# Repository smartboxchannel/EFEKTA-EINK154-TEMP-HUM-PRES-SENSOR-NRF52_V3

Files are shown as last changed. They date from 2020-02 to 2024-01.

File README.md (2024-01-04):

# EFEKTA-EINK154-TEMP-HUM-PRESS-SENSOR-NRF52

Телеграм чат DIY Devices - https://t.me/diy_devices

Продажа DIY Устройств - https://t.me/diydevmart

Temperature and humidity sensor with 1.54 e-ink display.

#### Don't donate to me, it doesn't work in this world: https://paypal.me/efektalab , just buy:

fully assembled - $45.5

Video: https://youtu.be/T66y83lF-xg

More info at http://efektalab.com/eink154 

---

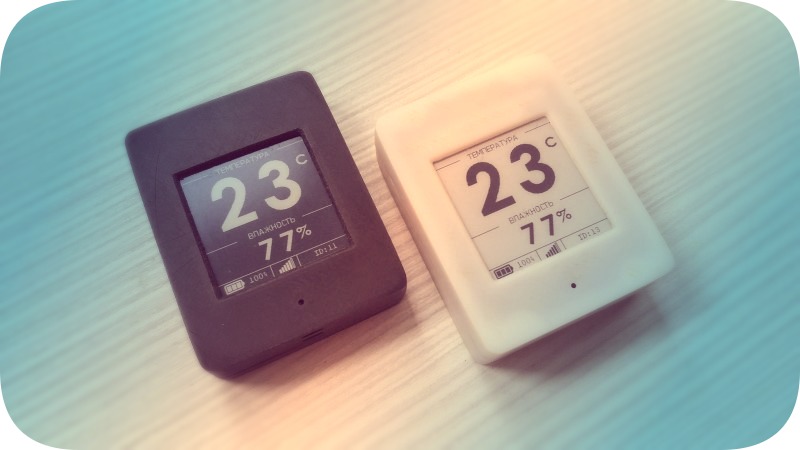
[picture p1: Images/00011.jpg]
EFEKTA EINK102 TEMP HUM MICRO SENSOR NRF52


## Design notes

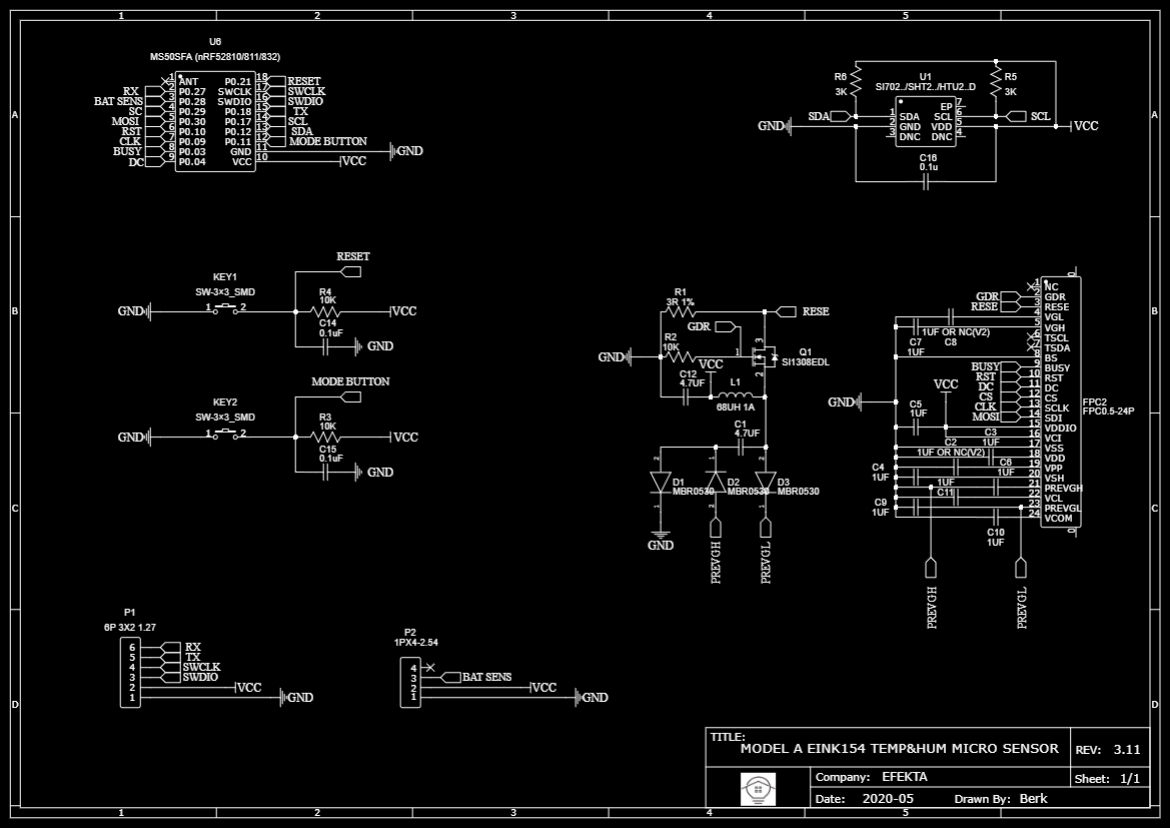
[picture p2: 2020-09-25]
Schematic_154v3T_A.png

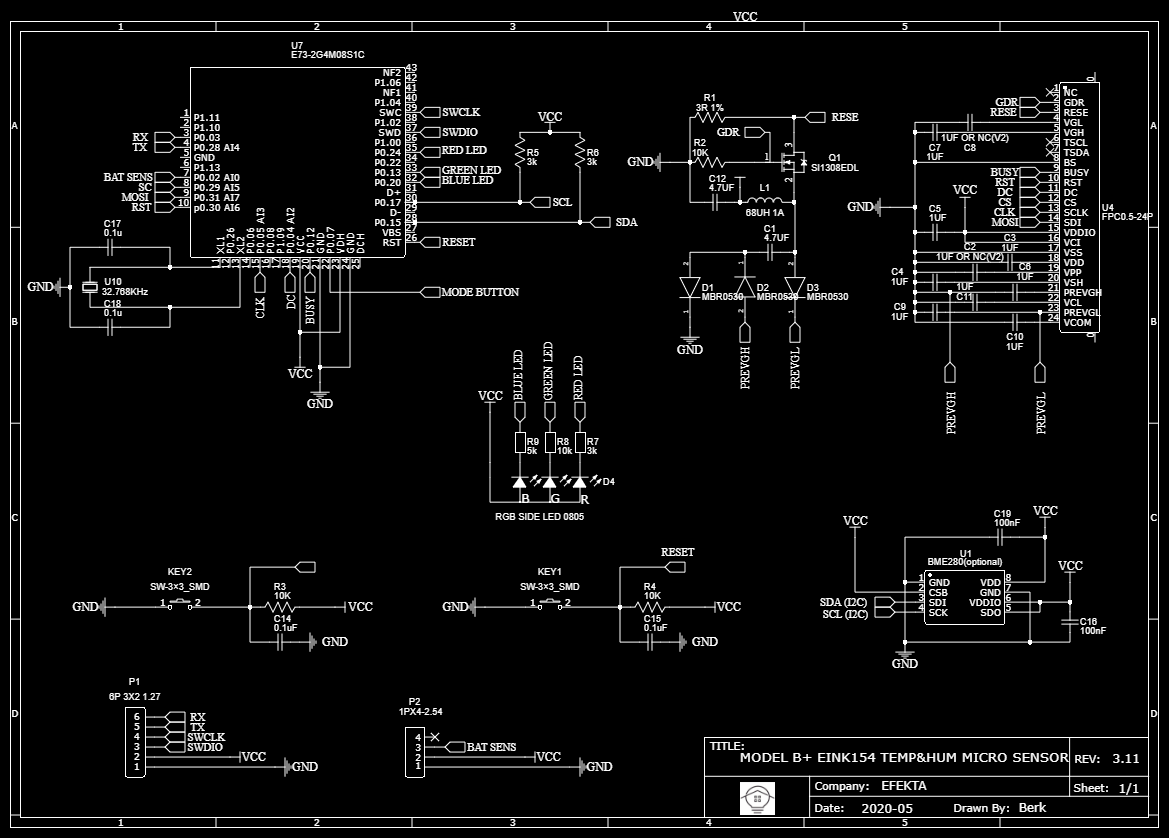
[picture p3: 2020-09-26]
SCHEME/Schematic_154v3T_B_plus.png

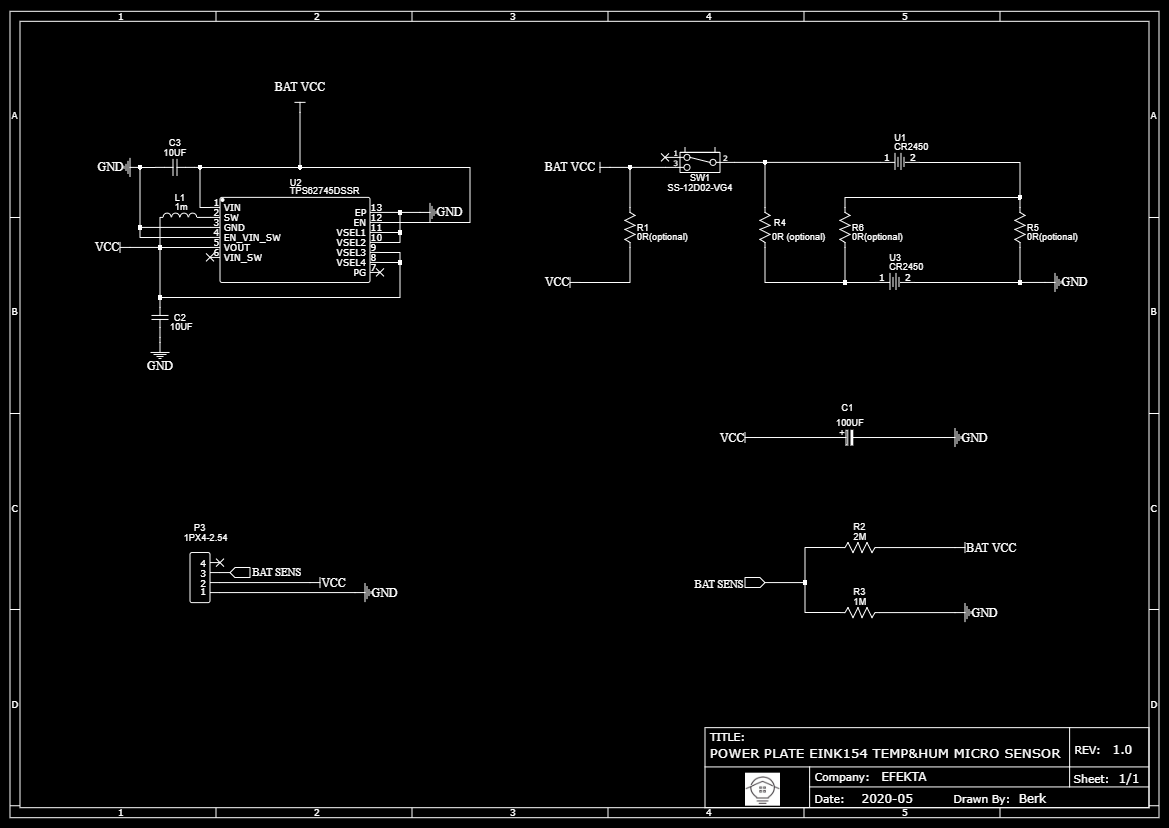
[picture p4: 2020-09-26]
SCHEME/Schematic_154v3B.png

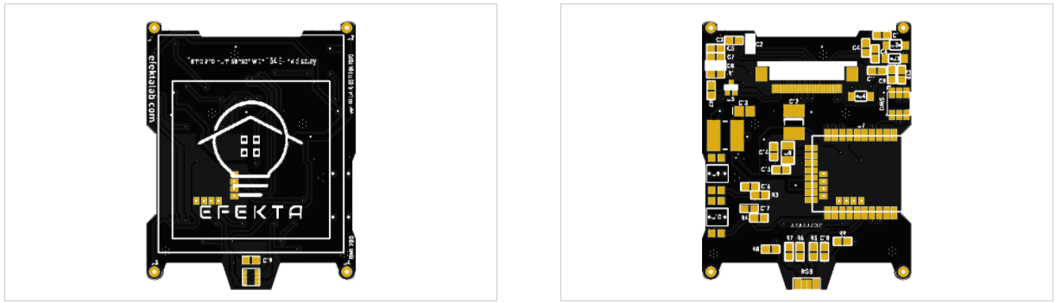
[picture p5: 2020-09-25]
Images/PCB_154v3T_B_plus.png

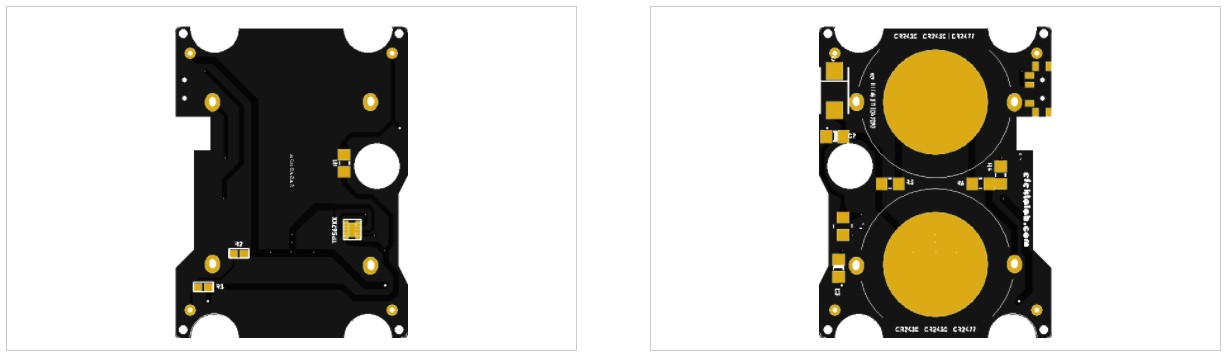
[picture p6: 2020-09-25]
Images/Bottom.jpg

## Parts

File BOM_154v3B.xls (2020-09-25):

ID | Name | Designator | Footprint | Quantity | URL
1 | CR2450 Holder | U1,U3 |  | 2 | https://lite.al/aQULIC
2 | TPS62745DSSR | U2 |  | 1 | https://lite.al/idG_8
3 | 1M | R2 | R0603 | 1 | https://lite.bz/_xQXIT
4 | 2M | R3 | R0603 | 1 | https://lite.bz/_xQXIT
5 | 0R | R1,R4,R5,R6 | R0603 | 4 | https://lite.al/wJH_j
6 | 10UF | C2,C3 | 1206 | 2 | https://lite.bz/Iua09
7 | 4.7UH | L1 | 1210 | 1 | https://lite.bz/1wrt-f
8 | 100uF | C13 | TANTAL 16V | 1 | https://lite.al/GeQyW
9 | SPDT MSK-12C02 SM | U2 |  | 1 | https://lite.al/ldulEe

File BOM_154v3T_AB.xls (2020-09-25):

ID | Name | Designator | Footprint | Quantity | URL
1 | GDEW0102T4 EINK1.54 |  |  | 1 | https://ali.ski/0pJURr
2 | GDEW0102T4 EINK1.54 |  |  | 1 | https://ali.ski/tIZry
3 | GDEW0102T4 EINK1.54 |  |  | 1 | https://ali.ski/WwyO3
4 | MS50SFA (nRF52810/811) | U7 | WIRELM-SMD_MS50SFA | 1 | https://ali.ski/8ya0Ob
5 | MS50SFA (nRF52811/832) | U7 | WIRELM-SMD_MS50SFA | 1 | https://ali.ski/gBDdnL
6 | E73-2G4M08S1C | U7 | WIRELM-SMD_E73-2G4M08S1C | 1 | https://ali.ski/ElGPh
7 | E73-2G4M08S1C | U7 | WIRELM-SMD_E73-2G4M08S1C | 1 | https://lite.al/qu4rE
8 | 4.7uF | C1,C12 | C0805 | 2 | https://ali.ski/7K6tZq
9 | 1uF (C2,C8 for V1 only) | C3,C4,C5,C6,C7,C9,C10,C11,C2,C8 | C0603 | 10 | https://lite.al/vsbI7N
10 | 100uF (if no SD Conv.) | C13 | TANTAL 10V | 1 | https://lite.al/mctVY
11 | 0.1uF | C14,C15,C16,C19 | C0603 | 5 | https://lite.al/eZrPr
12 | 22pF | C17,C18 | C0604 | 2 | https://lite.al/eZrPr
13 | SW-3×3_SMD | KEY1,KEY2 |  | 2 | https://lite.al/-qSRe
14 | 68uH or 100uH(V2) | L1 | D54 | 1 | https://lite.al/0V7Y2d
15 | 3R0 | R1 | R0603 | 1 | https://lite.al/wJH_j
16 | 10K | R2,R3,R4,R8 | R0603 | 4 | https://lite.al/wJH_j
17 | 3K | R7 | R0603 | 1 | https://lite.al/wJH_j
18 | 5K | R9 | R0603 | 1 | https://lite.al/wJH_j
19 | RGB SIDE LED | RGB | 1204 RGB | 1 | https://lite.bz/8izkIX
20 | MBR0530 | D1,D2,D3 | SOD-123 | 3 | https://lite.bz/aHLSRs
21 | FPC24 | U4 | FPC24 | 1 | https://lite.bz/tnF--R
22 | Si1304BD | U5 | SOT 323 | 1 | https://lite.al/apKJjP
23 | SHT20 | U1 |  | 1 | https://lite.bz/tGegZ
24 | Si7021 | U1 |  | 1 | https://lite.al/YWJ3c
25 | HTU21D | U1 |  | 1 | https://lite.bz/Qm9t30
26 | BME280 | U1 |  | 1 | https://lite.bz/FpaFS
27 | FC-135 | U10 | 3215 | 1 | https://lite.bz/DzxDDm

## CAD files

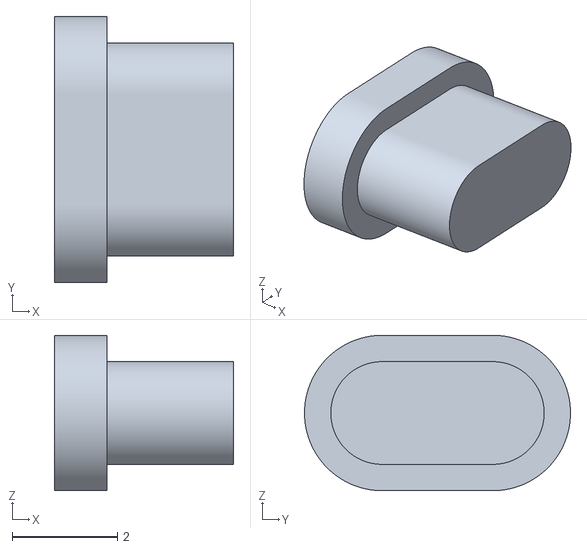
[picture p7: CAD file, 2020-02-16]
CASE/D_b.STL
3.40 x 5.05 x 2.95

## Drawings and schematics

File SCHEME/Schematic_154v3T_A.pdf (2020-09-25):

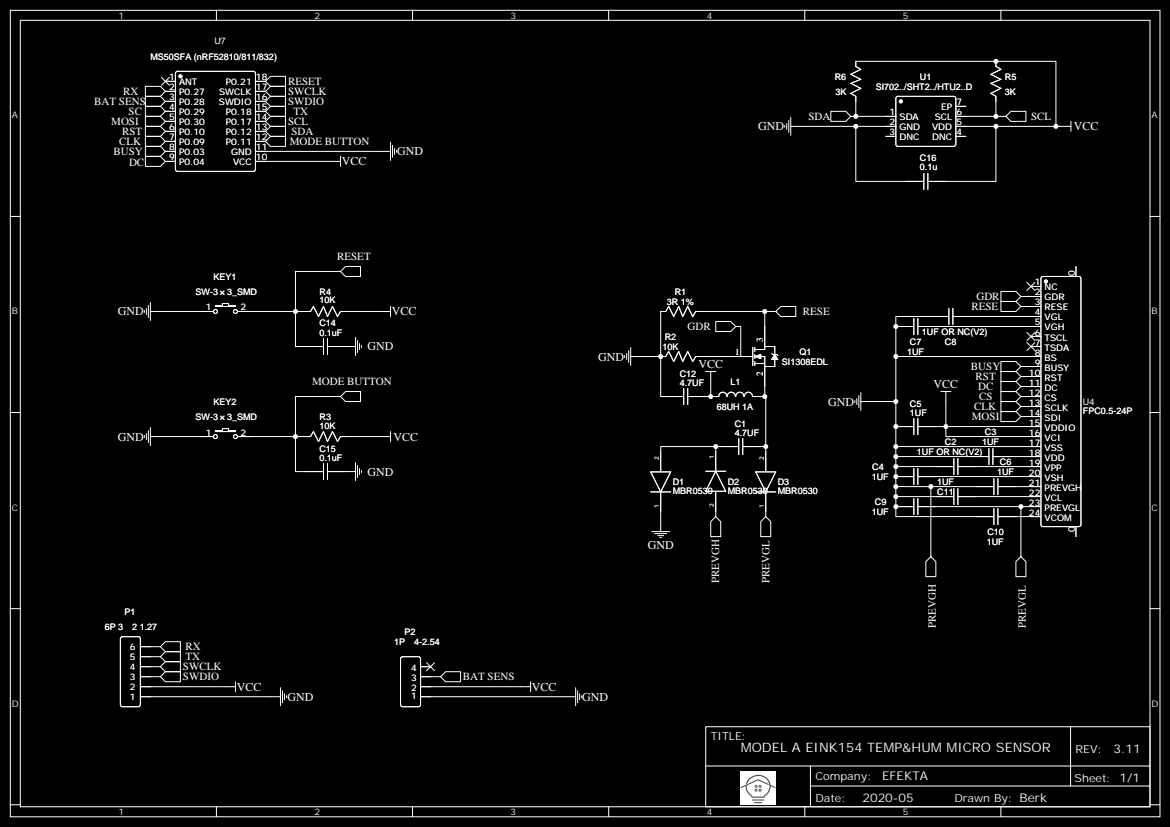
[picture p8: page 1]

VCC 10 GND 11 P0.11 12 P0.12 13 P0.17 14 P0.18 15 SWDIO 16 SWCLK 17 P0.21 18

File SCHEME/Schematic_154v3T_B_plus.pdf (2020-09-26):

RST 26 VBS 27 P0.15 28 D- 29 P0.17 30 D+ 31 P0.20 32 P0.13 33 P0.22 34 P0.24 35 P1.00 36 SWD 37 P1.02 38 SWC 39 P1.04 40 NF1 41 P1.06 42 NF2 43

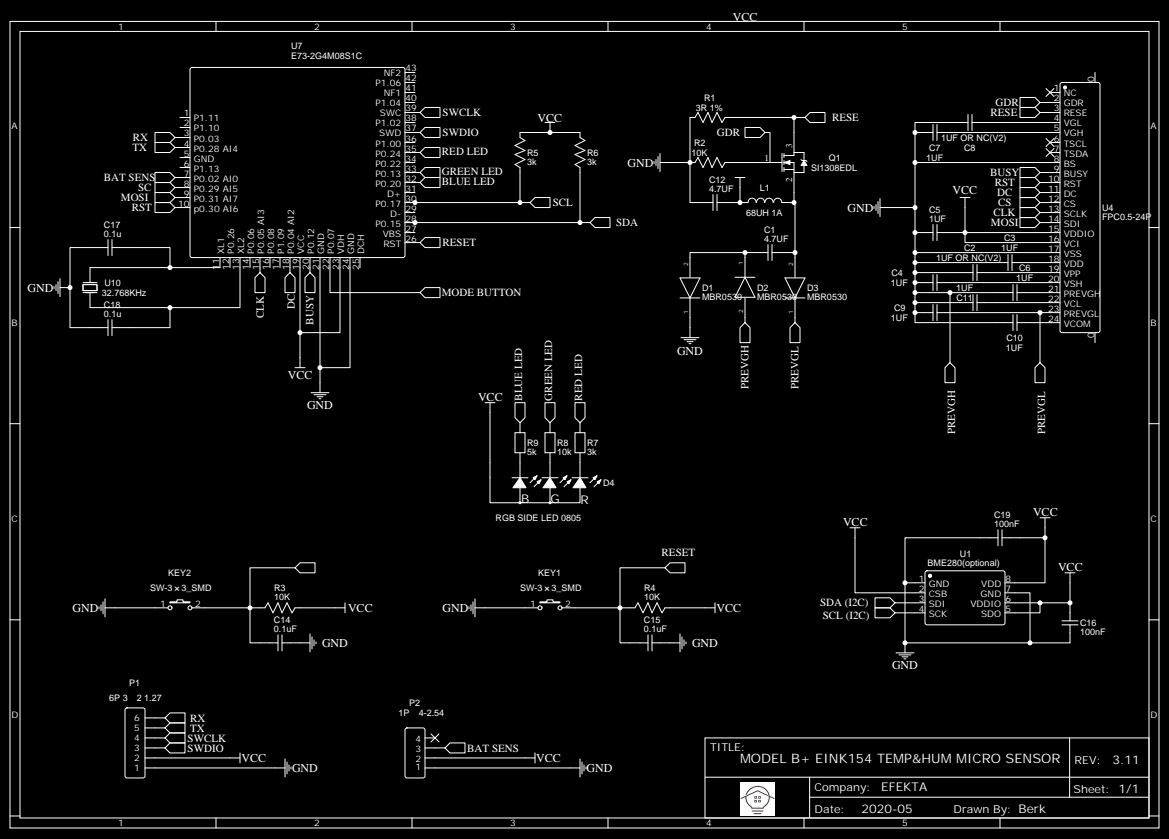
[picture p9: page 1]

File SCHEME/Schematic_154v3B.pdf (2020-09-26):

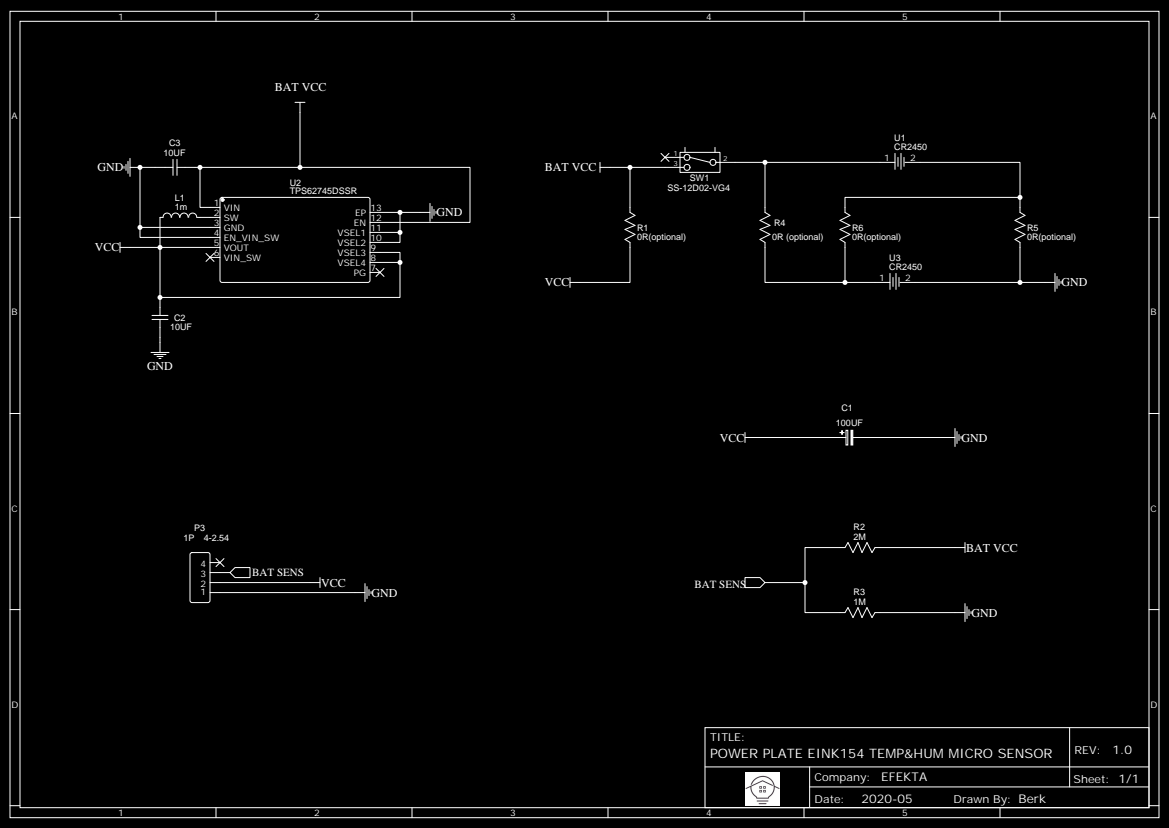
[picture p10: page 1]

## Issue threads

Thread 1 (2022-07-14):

Are there instructions to build?

84ace, 2022-07-14:
Hi,

Nice project! I am trying to build it using the Arduino IDE and I am not getting very far, as there are many errors. It seems like there are files missing (mymessages, for example), and there are lots of other errors that prevent the project from being built.

Is there something I am missing? Are you using the Arduino IDE?

Thanks,
84ace

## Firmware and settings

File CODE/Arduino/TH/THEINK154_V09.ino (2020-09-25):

// ######################  Temperature and humidity sensor with electronic ink display 1.54 | nRF52 ####################### //
//                                                                                                                          //
//        @filename   :   EFEKTA_THEINK154_1.9.ino                                                                          //
//        @brief en   :   Wireless, battery-operated temperature and humidity sensor (SHT20, SI7020)                        //
//                        with electronic ink display(good display). Works on nRF52.                                        //
//        @brief ru   :   Беcпроводной, батарейный датчик температуры и влажности(sht20, si7020)                            //
//                        с дисплеем на электронных чернилах(good display). Работает на nRF52.                              //
//        @author     :   Andrew Lamchenko aka Berk                                                                         //
//                                                                                                                          //
//        Copyright (C) EFEKTALAB 2020                                                                                      //
//                                                                                                                          //
// ######################################################################################################################## //

uint8_t colorPrint;
uint8_t opposite_colorPrint;
bool updateink1;
bool updateink2;
bool updateink3;
bool updateink4;
bool updateinkclear;
bool change;
bool chek_h = true;
bool first_send_battery = true;
bool check;
bool tch;
bool hch;
bool bch;
bool configMode;
bool button_flag;
bool nosleep;
bool flag_update_transport_param;
bool flag_sendRoute_parent;
bool flag_no_present;
bool flag_nogateway_mode;
bool flag_find_parent_process;
bool Ack_FP;

uint8_t lang;
uint8_t cpNom;
uint8_t cpCount;
uint8_t timeSend;
uint8_t battSend;
uint8_t battery;
uint8_t old_battery;
uint8_t err_delivery_beat;
uint8_t problem_mode_count;

float temperatureSend;
float humiditySend;
int16_t temperature;
int16_t humidity;
float old_temperature;
float old_humidity;
const float tempThreshold = 1.0;
const float humThreshold = 1.0;
int16_t nRFRSSI;
int16_t myid;
int16_t mypar;
int16_t old_mypar = -1;

uint16_t temp;
uint16_t batteryVoltage;
uint16_t minuteT = 60000;
uint16_t BATT_TIME;
uint16_t BATT_COUNT;

uint32_t configMillis;
uint32_t previousMillis;
uint32_t SLEEP_TIME;
const uint32_t SLEEP_TIME_WDT = 5000;
uint32_t sleepTimeCount;
const uint32_t shortWait = 50;

float batteryVoltageF;

#include "gdef.h"
#include "eink54.h"
#include "eink54paint.h"
#include "eink54imagedata.h"
unsigned char image[5200];
Paint paint(image, 200, 200);
Epd epd;
#ifdef SHT20
#include "DFRobot_SHT20.h"
DFRobot_SHT20    sensor; // https://github.com/DFRobot/DFRobot_SHT20
#endif

#ifdef SI7020
#include "Adafruit_Si7021.h" // https://github.com/adafruit/Adafruit_Si7021
Adafruit_Si7021 sensor = Adafruit_Si7021();
#endif

#ifndef MY_DEBUG
#define MY_DISABLED_SERIAL
#endif
#define MY_RADIO_NRF5_ESB

int16_t mtwr;
#define MY_TRANSPORT_WAIT_READY_MS (mtwr)

#define SN "EFEKTA T&H E-Ink"
#define SV "0.914"

#define TEMP_ID 1
#define HUM_ID 2
#define SIGNAL_Q_ID 100
#define BATTERY_VOLTAGE_ID 101
#define SET_TIME_SEND_ID 102
#define SET_BATT_SEND_ID 103
#define MY_SEND_RESET_REASON 105
#define SET_COLOR_ID 106


#include <MySensors.h>
MyMessage msgTemp(TEMP_ID, V_TEMP);
MyMessage msgHum(HUM_ID, V_HUM);
MyMessage sqMsg(SIGNAL_Q_ID, V_VAR1);
MyMessage bvMsg(BATTERY_VOLTAGE_ID, V_VAR1);
MyMessage setTimeSendMsg(SET_TIME_SEND_ID, V_VAR1);
MyMessage setBattSendMsg(SET_BATT_SEND_ID, V_VAR1);
MyMessage sendMsg(MY_SEND_RESET_REASON, V_VAR1);
MyMessage setColor(SET_COLOR_ID, V_VAR1);

// SDK PORT
uint32_t PIN_BUTTON_MASK;
volatile byte buttIntStatus = 0;
#define APP_GPIOTE_MAX_USERS 1
extern "C" {
#include "app_gpiote.h"
#include "nrf_gpio.h"
}
static app_gpiote_user_id_t m_gpiote_user_id;


void preHwInit() {
  pinMode(PIN_BUTTON, INPUT);
#if defined(EBYTE)
  pinMode(RED_LED, OUTPUT);
  pinMode(GREEN_LED, OUTPUT);
  pinMode(BLUE_LED, OUTPUT);
  digitalWrite(RED_LED, HIGH);
  digitalWrite(GREEN_LED, HIGH);
  digitalWrite(BLUE_LED, HIGH);
#endif
#ifdef DCDC_SDC
  pinMode(BATTERY_PIN, INPUT);
#endif
}


void before()
{
  //########################################## CONFIG MCU ###############################################

  NRF_POWER->DCDCEN = 1;
  NRF_SAADC ->ENABLE = 0;
  NRF_PWM0  ->ENABLE = 0;
#if defined(MINEW)
  NRF_TWIM0 ->ENABLE = 0;
  NRF_TWIS0 ->ENABLE = 0;
  NRF_RADIO->TXPOWER = 0x4UL;
#else
  NRF_NFCT->TASKS_DISABLE = 1;
  NRF_NVMC->CONFIG = 1;
  NRF_UICR->NFCPINS = 0;
  NRF_NVMC->CONFIG = 0;
  NRF_PWM1  ->ENABLE = 0;
  NRF_PWM2  ->ENABLE = 0;
  NRF_TWIM1 ->ENABLE = 0;
  NRF_TWIS1 ->ENABLE = 0;
  NRF_RADIO->TXPOWER = 0x8UL;
#endif

#ifdef DCDC_SDC
  analogReadResolution(12);
  analogReference(AR_VDD4);
#endif


  //########################################## INIT HAPPY ##############################################

  happy_init();


  //########################################## CONFIG PROG ###############################################

  timeSend = loadState(102);
  if (timeSend > 30) {
    timeSend = 1;
    saveState(102, timeSend);
  }
  //timeSend = 1; // для теста, 1 минута

  battSend = loadState(103);
  if (battSend > 24) {
    battSend = 3;
    saveState(103, battSend);
  }
  battSend = 1; // для теста, 1 час

  if (loadState(106) > 1) {
    saveState(106, 0);
  }
  colorChange(loadState(106));
  //colorChange(false); // для теста, true или false

  timeConf();


  //########################################## EINK INIT ###############################################
  epd.Init(lut_full_update);
  clearOne();
  epd.Init(lut_partial_update);
  DrawImageWH(&epd, &paint, 40, 30, LOGO, 140, 116, colorPrint, ROTATE_270);
  epd.DisplayFrame();
  delay(2500);
  clearOne();
  DrawImageWH(&epd, &paint, 10, 40, IMAGE_DATA4, 137, 180, colorPrint, ROTATE_270);
  epd.DisplayFrame();
  delay(3500);
  clearOne();
#ifdef DEVICE_PRESENT
#if defined(EBYTE)
  DrawImageWH(&epd, &paint, 36, 90, IMAGE_DATA2, 100, 121, colorPrint, ROTATE_90);
  DrawImageWH(&epd, &paint, 10, 20, IMAGE_DATA3, 62, 180, colorPrint, ROTATE_270);
  epd.DisplayFrame();
  delay(500);
  clearOne();
  DrawImageWH(&epd, &paint, 36, 130, IMAGE_DATA6, 40, 140, colorPrint, ROTATE_270);
  DrawImageWH(&epd, &paint, 36, 30, IMAGE_DATA5, 98, 140, colorPrint, ROTATE_270);
  epd.DisplayFrame();
  delay(500);
  clearOne();
  DrawImageWH(&epd, &paint, 38, 150, IMAGE_DATA7, 24, 130, colorPrint, ROTATE_270);
  DrawImageWH(&epd, &paint, 10, 70, IMAGE_DATA8, 62, 180, colorPrint, ROTATE_270);
  DrawImageWH(&epd, &paint, 61, 50, IMAGE_DATA9, 20, 82, colorPrint, ROTATE_270);
  epd.DisplayFrame();
  delay(500);
#endif
#endif

#ifdef LANG_RU
  DrawImageWH(&epd, &paint, 30, 80, NCON_RU, 43, 150, colorPrint, ROTATE_270);
#endif
#ifdef LANG_DE
  DrawImageWH(&epd, &paint, 30, 80, NCON_DE, 43, 150, colorPrint, ROTATE_270);
#endif
#ifdef LANG_FR
  DrawImageWH(&epd, &paint, 30, 80, NCON_FR, 43, 150, colorPrint, ROTATE_270);
#endif
#ifdef LANG_ESP
  DrawImageWH(&epd, &paint, 30, 80, NCON_ESP, 43, 150, colorPrint, ROTATE_270);
#endif
#ifdef LANG_HI
  DrawImageWH(&epd, &paint, 30, 80, NCON_HI, 43, 150, colorPrint, ROTATE_270);
#endif
#ifdef LANG_ZHO
  DrawImageWH(&epd, &paint, 30, 80, NCON_ZHO, 43, 150, colorPrint, ROTATE_270);
#endif
#ifdef LANG_EN
  DrawImageWH(&epd, &paint, 30, 80, NCON_ENG, 43, 150, colorPrint, ROTATE_270);
#endif
  epd.DisplayFrame();
  e_Ink_Deep_Sleep();
}


void presentation()
{
  check = sendSketchInfo(SN, SV);
  if (!check) {
    _transportSM.failedUplinkTransmissions = 0;
    wait(shortWait);
    check = sendSketchInfo(SN, SV);
    wait(shortWait * 2);
    _transportSM.failedUplinkTransmissions = 0;
  }

  check = present(TEMP_ID, S_TEMP, "Temperature");
  if (!check) {
    _transportSM.failedUplinkTransmissions = 0;
    wait(shortWait);
    check = present(TEMP_ID, S_TEMP, "Temperature");
    wait(shortWait * 2);
    _transportSM.failedUplinkTransmissions = 0;
  }

  check = present(HUM_ID, S_HUM, "Humidity");
  if (!check) {
    _transportSM.failedUplinkTransmissions = 0;
    wait(shortWait);
    check = present(HUM_ID, S_HUM, "Humidity");
    wait(shortWait * 2);
    _transportSM.failedUplinkTransmissions = 0;
  }

  check = present(SIGNAL_Q_ID, S_CUSTOM, "SIGNAL %");
  if (!check) {
    _transportSM.failedUplinkTransmissions = 0;
    wait(shortWait);
    check = present(SIGNAL_Q_ID, S_CUSTOM, "SIGNAL %");
    wait(shortWait * 2);
    _transportSM.failedUplinkTransmissions = 0;
  }

  check = present(BATTERY_VOLTAGE_ID, S_CUSTOM, "BATTERY VOLTAGE");
  if (!check) {
    _transportSM.failedUplinkTransmissions = 0;
    wait(shortWait);
    check = present(BATTERY_VOLTAGE_ID, S_CUSTOM, "BATTERY VOLTAGE");
    wait(shortWait * 2);
    _transportSM.failedUplinkTransmissions = 0;
  }

  check = present(SET_TIME_SEND_ID, S_CUSTOM, "T&H SEND INTERVAL | Min");
  if (!check) {
    _transportSM.failedUplinkTransmissions = 0;
    wait(shortWait);
    check = present(SET_TIME_SEND_ID, S_CUSTOM, "T&H SEND INTERVAL | Min");
    wait(shortWait * 2);
    _transportSM.failedUplinkTransmissions = 0;
  }

  check = present(SET_BATT_SEND_ID, S_CUSTOM, "BATT SEND INTERTVAL | H");
  if (!check) {
    _transportSM.failedUplinkTransmissions = 0;
    wait(shortWait);
    check = present(SET_BATT_SEND_ID, S_CUSTOM, "BATT SEND INTERTVAL | H");
    wait(shortWait * 2);
    _transportSM.failedUplinkTransmissions = 0;
  }

  check = present(MY_SEND_RESET_REASON, S_CUSTOM, "RESTART REASON");
  if (!check) {
    _transportSM.failedUplinkTransmissions = 0;
    wait(shortWait);
    check = present(MY_SEND_RESET_REASON, S_CUSTOM, "RESTART REASON");
    wait(shortWait * 2);
    _transportSM.failedUplinkTransmissions = 0;
  }

  check = present(SET_COLOR_ID, S_CUSTOM, "COLOR W/B");
  if (!check) {
    _transportSM.failedUplinkTransmissions = 0;
    wait(shortWait);
    check = present(SET_COLOR_ID, S_CUSTOM, "COLOR W/B");
    wait(shortWait * 2);
    _transportSM.failedUplinkTransmissions = 0;
  }
  wait(shortWait * 2);
  sendConfig();
  wait(shortWait);
}


void setup() {
  CORE_DEBUG(PSTR("MyS: CONFIG HAPPY NODE\n"));
  config_Happy_node();
  CORE_DEBUG(PSTR("MyS: READ BATTERY VOLTAGE\n"));
  readBatt();
  CORE_DEBUG(PSTR("MyS: SEND CONFIG PARAMETERS\n"));
  if (flag_nogateway_mode == false) {
    wait(shortWait);
    sendResetReason();
  }
  CORE_DEBUG(PSTR("MyS: INTERRUPT CONFIG\n"));
  interrupt_Init();
  CORE_DEBUG(PSTR("MyS: DISABLE RADIO\n"));
  transportDisable();
  sleepTimeCount = SLEEP_TIME;
#ifdef SHT20
  sensor.initSHT20();
#endif
#ifdef SI7020
  sensor.begin();
#endif
  wait(shortWait);
  CORE_DEBUG(PSTR("MyS: WDT ENABLE\n"));
  wdt_enable();
}


void loop() {
  if (flag_update_transport_param == true) {
    update_Happy_transport();
  }
  if (flag_sendRoute_parent == true) {
    present_only_parent();
  }
  if (isTransportReady() == true) {
    if (flag_nogateway_mode == false) {
      if (flag_find_parent_process == true) {
        find_parent_process();
      }

      if (configMode == false) {
        if (buttIntStatus == PIN_BUTTON) {
          if (digitalRead(PIN_BUTTON) == LOW && button_flag == false) {
            wdt_nrfReset();
            epd.Reset();
            button_flag = true;
            previousMillis = millis();
          }
          if (digitalRead(PIN_BUTTON) == LOW && button_flag == true) {
            if ((millis() - previousMillis > 0) && (millis() - previousMillis <= 4500)) {
              if (updateink1 == false) {
                einkZeropush();
                updateink1 = true;
              }
            }
            if ((millis() - previousMillis > 4500) && (millis() - previousMillis <= 5500)) {
              if (updateinkclear == false) {
                clearOne();
                updateinkclear = true;
              }
            }
            if ((millis() - previousMillis > 5500) && (millis() - previousMillis <= 8500)) {
              if (updateink2 == false) {
                einkOnepush();
                updateink2 = true;
                updateinkclear = false;
              }
            }
            if ((millis() - previousMillis > 8500) && (millis() - previousMillis <= 9500)) {
              if (updateinkclear == false) {
                clearOne();
                updateinkclear = true;
              }
            }
            if ((millis() - previousMillis > 9500) && (millis() - previousMillis <= 12500)) {
              if (updateink4 == false) {
                einkTwopush();
                updateink4 = true;
                updateinkclear = false;
              }
            }
            if (millis() - previousMillis > 12500) {
              if (updateinkclear == false) {
                clearOne();
                updateinkclear = true;
              }
            }
          }
          if (digitalRead(PIN_BUTTON) == HIGH && button_flag == true) {

            if ((millis() - previousMillis <= 4500) && (button_flag == true))
            {
              wdt_nrfReset();
              einkZeroend();
              reseteinkset();
              button_flag = false;
              buttIntStatus = 0;
              transportReInitialise();
              presentation();
              transportDisable();
              change = true;
              sleepTimeCount = SLEEP_TIME;
            }
            if ((millis() - previousMillis > 5500 && millis() - previousMillis <= 8500) && button_flag == true)
            {
              wdt_nrfReset();
              einkOneend();
              reseteinkset();
              configMode = true;
              button_flag = false;
              buttIntStatus = 0;
              transportReInitialise();
              wait(shortWait);
              NRF5_ESB_startListening();
              wait(shortWait);
              configMillis = millis();
            }
            if ((millis() - previousMillis > 9500) && (millis() - previousMillis <= 12500) && (button_flag == true))
            {
              einkTwoend();
              new_device();
            }
            if ((((millis() - previousMillis > 4500) && (millis() - previousMillis <= 5500)) || ((millis() - previousMillis > 8500) && (millis() - previousMillis <= 9500)) || (millis() - previousMillis > 12500) ) && (button_flag == true) )
            {
              wdt_nrfReset();
              change = true;
              sleepTimeCount = SLEEP_TIME;
              reseteinkset();
              button_flag = false;
              buttIntStatus = 0;
            }
          }
          wdt_nrfReset();
        } else {
          sleepTimeCount++;
          nosleep = false;
          wait(10);
          if (!nosleep) {
            nosleep = false;
            wait(10);
          }
          wdt_nrfReset();
          if (sleepTimeCount >= SLEEP_TIME) {
            sleepTimeCount = 0;
            readData();
            if (change == true) {
              change = false;
              wait(shortWait);
              transportReInitialise();
              wait(shortWait);
              sendData();
              transportDisable();
              wait(shortWait);
              epd.Reset();
              wait(shortWait);
              convert(temperature, humidity);
              wait(shortWait);
              e_Ink_Deep_Sleep();
            }
          }
          nosleep = false;
        }
      } else {
        if (millis() - configMillis > 15000) {
          configMode = false;
          button_flag = false;
          buttIntStatus = 0;
          transportDisable();
          wait(shortWait * 2);
          change = true;
          sleepTimeCount = SLEEP_TIME;
#if defined(EBYTE)
          digitalWrite(GREEN_LED, LOW);
          wait(50);
          digitalWrite(GREEN_LED, HIGH);
#endif
        }
        wdt_nrfReset();
      }
    } else {
      if (buttIntStatus == PIN_BUTTON) {
        if (digitalRead(PIN_BUTTON) == LOW && button_flag == false) {
          wdt_nrfReset();
          epd.Reset();
          button_flag = true;
          previousMillis = millis();
        }
        if (digitalRead(PIN_BUTTON) == LOW && button_flag == true) {
          if ((millis() - previousMillis > 0) && (millis() - previousMillis <= 4500)) {
            if (updateink1 == false) {
              einkZeropush();
              updateink1 = true;
            }
          }
          if ((millis() - previousMillis > 4500) && (millis() - previousMillis <= 5500)) {
            if (updateinkclear == false) {
              clearOne();
              updateinkclear = true;
            }
          }
          if ((millis() - previousMillis > 5500) && (millis() - previousMillis <= 8500)) {
            if (updateink4 == false) {
              einkTwopush();
              updateink4 = true;
              updateinkclear = false;
            }
          }
          if (millis() - previousMillis > 8500) {
            if (updateinkclear == false) {
              clearOne();
              updateinkclear = true;
            }
          }
        }
        if (digitalRead(PIN_BUTTON) == HIGH && button_flag == true) {
          if (millis() - previousMillis <= 4500 && button_flag == true)
          {
            wdt_nrfReset();
            einkZeroend();
            reseteinkset();
            button_flag = false;
            buttIntStatus = 0;
            transportReInitialise();
            check_parent();
            cpCount = 0;
            change = true;
            sleepTimeCount = SLEEP_TIME;
          }
          if ((millis() - previousMillis > 5500) && (millis() - previousMillis <= 8500) && (button_flag == true))
          {
            einkTwoend();
            new_device();
          }
          if ( ( ( millis() - previousMillis > 4500 && millis() - previousMillis <= 5500 ) || ( millis() - previousMillis > 8500)) && button_flag == true)
          {
            wdt_nrfReset();
            change = true;
            sleepTimeCount = SLEEP_TIME;
            reseteinkset();
            button_flag = false;
            buttIntStatus = 0;
          }
        }
        wdt_nrfReset();
      } else {
        sleepTimeCount++;
        if (sleepTimeCount >= SLEEP_TIME) {
          sleepTimeCount = 0;
          readData();
          if (change == true) {
            change = false;
            wait(shortWait);
            transportReInitialise();
            wait(shortWait);
            sendData();
            transportDisable();
            wait(shortWait);
            epd.Reset();
            wait(shortWait);
            convert(temperature, humidity);
            wait(shortWait);
            e_Ink_Deep_Sleep();
          }
          sleepTimeCount = 0;
          cpCount++;
          if (cpCount >= cpNom) {
            transportReInitialise();
            check_parent();
            cpCount = 0;
          }
        }
        if ((cpCount < cpNom) && (flag_nogateway_mode == true)) {
          nosleep = false;
        }
      }
    }
  }
  if (_transportSM.failureCounter > 0)
  {
    _transportConfig.parentNodeId = loadState(201);
    _transportConfig.nodeId = myid;
    _transportConfig.distanceGW = loadState(202);
    mypar = _transportConfig.parentNodeId;
    nosleep = false;
    err_delivery_beat = 6;
    happy_node_mode();
    gateway_fail();
  }

  if (nosleep == false) {
    wdt_nrfReset();
    hwSleep(SLEEP_TIME_WDT);
    nosleep = true;
  }
  wdt_nrfReset();
}


//################################################### EINK ###################################################

void DrawImageWH(Epd * epd, Paint * paint, int X, int Y, const uint8_t* imgData, int Width, int Height, uint8_t intcolored, int Rotate )
{
  if (Rotate == ROTATE_90 || Rotate == ROTATE_270) {
    paint->SetWidth(Height);
    paint->SetHeight(Width);
  } else {
    paint->SetWidth(Width);
    paint->SetHeight(Height);
  }
  paint->SetRotate(Rotate);

  if (intcolored == 0x00) {
    paint->Clear(0xFF);
  } else {
    paint->Clear(0x00);
  }

  int i, j;
  const unsigned char* prt = imgData;
  for (j = 0; j < Height; j++) {
    for (i = 0; i < Width; i++) {
      if (pgm_read_byte(prt) & (0x80 >> (i % 8))) {
        paint->DrawPixel(i, j, intcolored);
      }
      if (i % 8 == 7) {
        prt++;
      }
    }
    if (Width % 8 != 0) {
      prt++;
    }
  }
  epd->SetFrameMemory(paint->GetImage(), X, Y, paint->GetWidth(), paint->GetHeight());
}


void clearOne() {
  epd.ClearFrameMemory(opposite_colorPrint);
  epd.DisplayFrame();
  if (colorPrint == 0xFF) {
    epd.ClearFrameMemory(colorPrint);
    epd.DisplayFrame();
  } else {
    epd.ClearFrameMemory(opposite_colorPrint);
    epd.DisplayFrame();
  }
}


void e_Ink_Deep_Sleep() {
  epd.Init(lut_partial_update);
  wait(10);
  epd.SendCommand(0x10);
  wait(10);
  epd.SendData(0x01);
  wait(130);
}


void reseteinkset() {
  updateink1 = false;
  updateink2 = false;
  updateink3 = false;
  updateink4 = false;
  updateinkclear = false;
}


void einkZeropush() {

  clearOne();
#ifdef LANG_RU
  DrawImageWH(&epd, &paint, 30, 95, BUTT_ZERO_RU, 36, 150, colorPrint, ROTATE_270);
#endif
#ifdef LANG_ESP
  DrawImageWH(&epd, &paint, 30, 95, BUTT_ZERO_ESP, 36, 150, colorPrint, ROTATE_270);
#endif
#ifdef LANG_DE
  DrawImageWH(&epd, &paint, 30, 95, BUTT_ZERO_DE, 36, 150, colorPrint, ROTATE_270);
#endif
#ifdef LANG_FR
  DrawImageWH(&epd, &paint, 30, 95, BUTT_ZERO_FR, 36, 150, colorPrint, ROTATE_270);
#endif
#ifdef LANG_HI
  DrawImageWH(&epd, &paint, 30, 95, BUTT_ZERO_HI, 36, 150, colorPrint, ROTATE_270);
#endif
#ifdef LANG_ZHO
  DrawImageWH(&epd, &paint, 30, 95, BUTT_ZERO_ZHO, 36, 150, colorPrint, ROTATE_270);
#endif
#ifdef LANG_EN
  DrawImageWH(&epd, &paint, 30, 95, BUTT_ZERO_ENG, 36, 150, colorPrint, ROTATE_270);
#endif
  epd.DisplayFrame();
}
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

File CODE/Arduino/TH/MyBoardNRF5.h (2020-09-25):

// ######################  Temperature and humidity sensor with electronic ink display 1.54 | nRF52 ####################### //
//                                                                                                                          //
//        @filename   :   EFEKTA_THEINK154_1.8.ino                                                                          //
//        @brief en   :   Wireless, battery-operated temperature and humidity sensor (SHT20, SI7020)                        //
//                        with electronic ink display(good display). Works on nRF52.                                        //
//        @brief ru   :   Беcпроводной, батарейный датчик температуры и влажности(sht20, si7020)                            //
//                        с дисплеем на электронных чернилах(good display). Работает на nRF52.                              //
//        @author     :   Andrew Lamchenko aka Berk                                                                         //
//                                                                                                                          //
//        Copyright (C) EFEKTALAB 2020                                                                                      //
//                                                                                                                          //
// ######################################################################################################################## //

#ifndef _MYBOARDNRF5_H_
#define _MYBOARDNRF5_H_

#include "gdef.h"

#ifdef __cplusplus
extern "C"
{
#endif // __cplusplus

// Number of pins defined in PinDescription array
#define PINS_COUNT           (32u)
#define NUM_DIGITAL_PINS     (32u)
#define NUM_ANALOG_INPUTS    (8u)
#define NUM_ANALOG_OUTPUTS   (8u)


//   LEDs

#if defined(HOLYIOT)
#define PIN_LED1              (8)
#define LED_BUILTIN           PIN_LED1
#elif defined(EBYTE)
#define PIN_LED1              (24)
#define PIN_LED2              (20)
#define PIN_LED3              (13)
#define BLUE_LED               (PIN_LED2)
#define GREEN_LED             (PIN_LED3)
#define RED_LED              (PIN_LED1)
#define LED_BUILTIN           (PIN_LED1)
#endif


  //   Buttons

#if defined(MINEW)
#define PIN_BUTTON             (11)
#elif defined(HOLYIOT)
#define PIN_BUTTON             (19)
#elif defined(EBYTE)
#define PIN_BUTTON             (7)
#endif

#ifdef DCDC_SDC
#define BATTERY_PIN             (2)
#endif

#if defined(MINEW)
#define RST_PIN         10
#define DC_PIN          4
#define CS_PIN          29
#define BUSY_PIN        3
#elif defined(EBYTE)
#define RST_PIN         (30)
#define DC_PIN          (4)
#define CS_PIN          (29)
#define BUSY_PIN        (12)
#elif defined(HOLYIOT)
#define RST_PIN         (17)
#define DC_PIN          (16)
#define CS_PIN          (5)
#define BUSY_PIN        (15)
#endif

    /*
       Analog ports

       If you change g_APinDescription, replace PIN_AIN0 with
       port numbers mapped by the g_APinDescription Array.
       You can add PIN_AIN0 to the g_APinDescription Array if
       you want provide analog ports MCU independed, you can add
       PIN_AIN0..PIN_AIN7 to your custom g_APinDescription Array
       defined in MyBoardNRF5.cpp
    */
static const uint8_t A0  = ADC_A0;
static const uint8_t A1  = ADC_A1;
static const uint8_t A2  = ADC_A2;
static const uint8_t A3  = ADC_A3;
static const uint8_t A4  = ADC_A4;
static const uint8_t A5  = ADC_A5;
static const uint8_t A6  = ADC_A6;
static const uint8_t A7  = ADC_A7;

/*
   Serial interfaces

   RX and TX are required.
   If you have no serial port, use unused pins
   CTS and RTS are optional.
*/
#if defined(MINEW)
#define PIN_SERIAL_RX       (27)
#define PIN_SERIAL_TX       (18)
#elif defined(HOLYIOT)
#define PIN_SERIAL_RX       (12)
#define PIN_SERIAL_TX       (11)
#elif defined(EBYTE)
#define PIN_SERIAL_RX       (3)
#define PIN_SERIAL_TX       (28)
#endif
/*
   SPI Interfaces

   This is optional

   If SPI is defined MISO, MOSI, SCK are required
   SS is optional and can be used in your sketch.
*/
#define SPI_INTERFACES_COUNT 1

#if defined(MINEW)
#define PIN_SPI_MISO         (2)
#define PIN_SPI_MOSI         (30)
#define PIN_SPI_SCK          (9)
#define PIN_SPI_SS           (29)
#elif defined(HOLYIOT)
#define PIN_SPI_MISO         (2)
#define PIN_SPI_MOSI         (3)
#define PIN_SPI_SCK          (4)
#define PIN_SPI_SS           (5)
#elif defined(EBYTE)
#define PIN_SPI_MISO         (22)
#define PIN_SPI_MOSI         (31)
#define PIN_SPI_SCK          (5)
#define PIN_SPI_SS           (29)
#endif

static const uint8_t SS   = PIN_SPI_SS;
static const uint8_t MOSI = PIN_SPI_MOSI;
static const uint8_t MISO = PIN_SPI_MISO;
static const uint8_t SCK  = PIN_SPI_SCK;

/*
   Wire Interfaces

   This is optional
*/
#define WIRE_INTERFACES_COUNT 2
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
